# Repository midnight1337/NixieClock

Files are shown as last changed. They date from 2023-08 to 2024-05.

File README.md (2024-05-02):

# Nixie Clock

## Overwiev

Nixie clock is a retro style clock based on cool looking, vintage Nixie Tubes. <br/>

This project is inspired by GreatScott, however I've written my own code for driving this device, and did some changes in board by adding microswitches that allows user to change time manually.

Clock displays time in Hour::Minute segments. Board contains a RTC module that can track time with no power supply.

DS3231 clock library made by https://www.jarzebski.pl/arduino/komponenty/zegar-czasu-rzeczywistego-rtc-ds3231.html,
however I had to do some modifications for my needs.

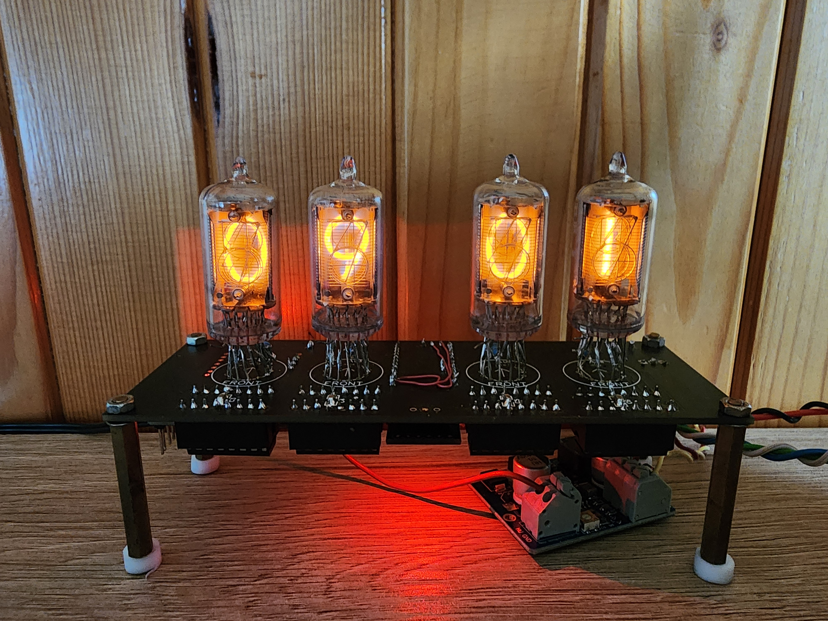
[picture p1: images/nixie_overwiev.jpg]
Overwiev


### Technologies and Development
- Arduino Pro Mini
- C++
- Electrical Engineering

## UML
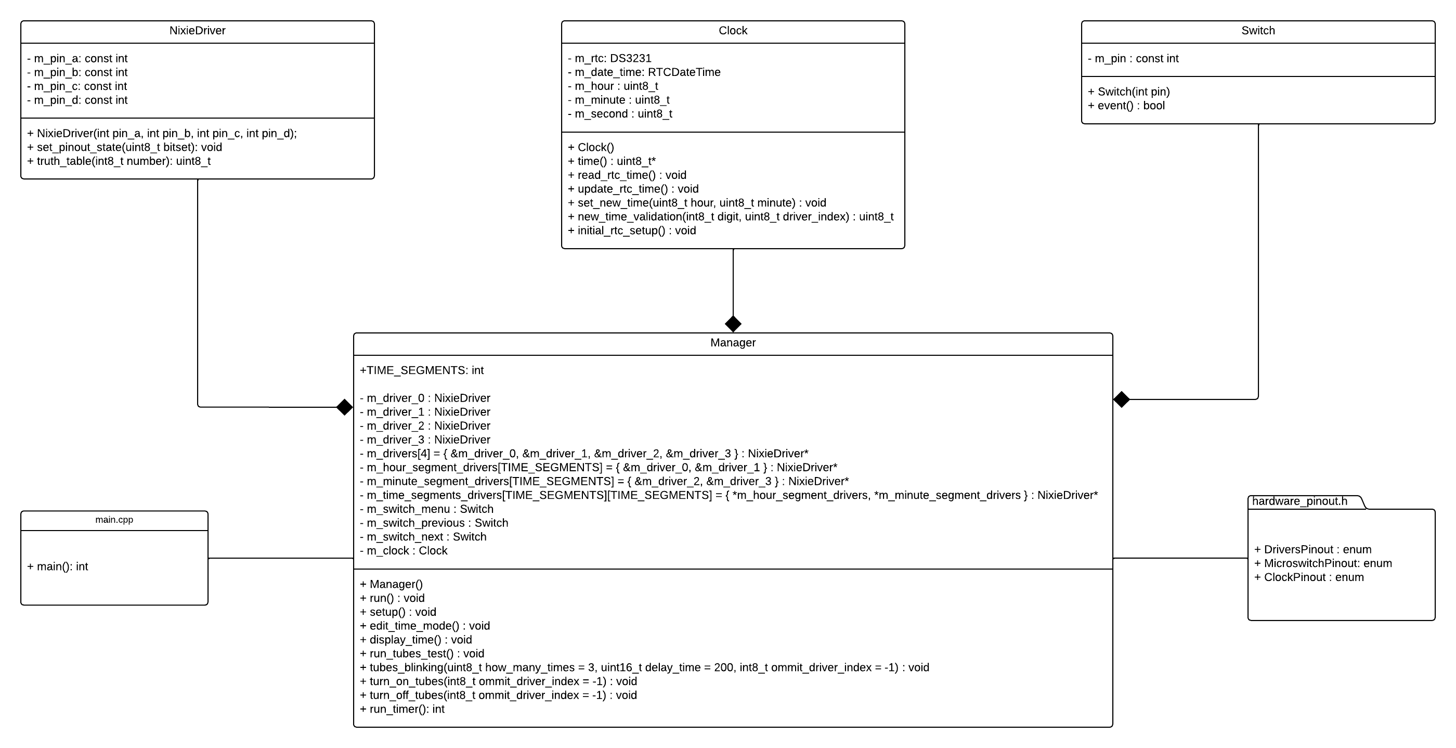
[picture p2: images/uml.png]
UML


## Schematic
...

## Project documentation

#### Testing nixie tubes:
At the beginning of my project I had to choose working Tubes by building simple driver circuit and running each digit from 0 to 9. As you may know they are very old and well worn. Some of them that I had, were damaged, or cathodes were burned out.
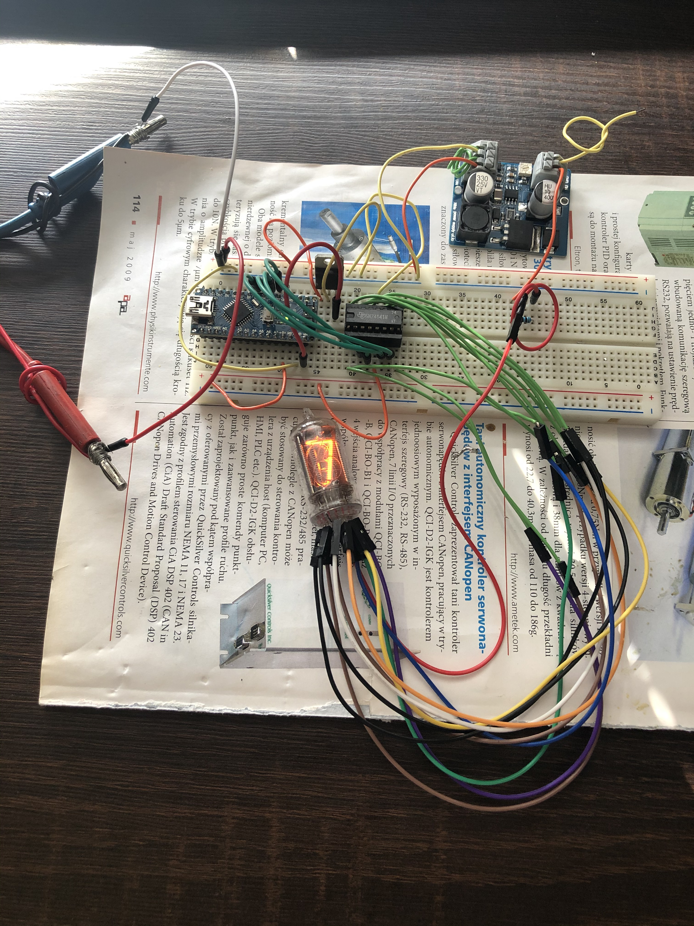
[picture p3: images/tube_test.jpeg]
Tube Test


#### Prototype:
First power up with everything on board.
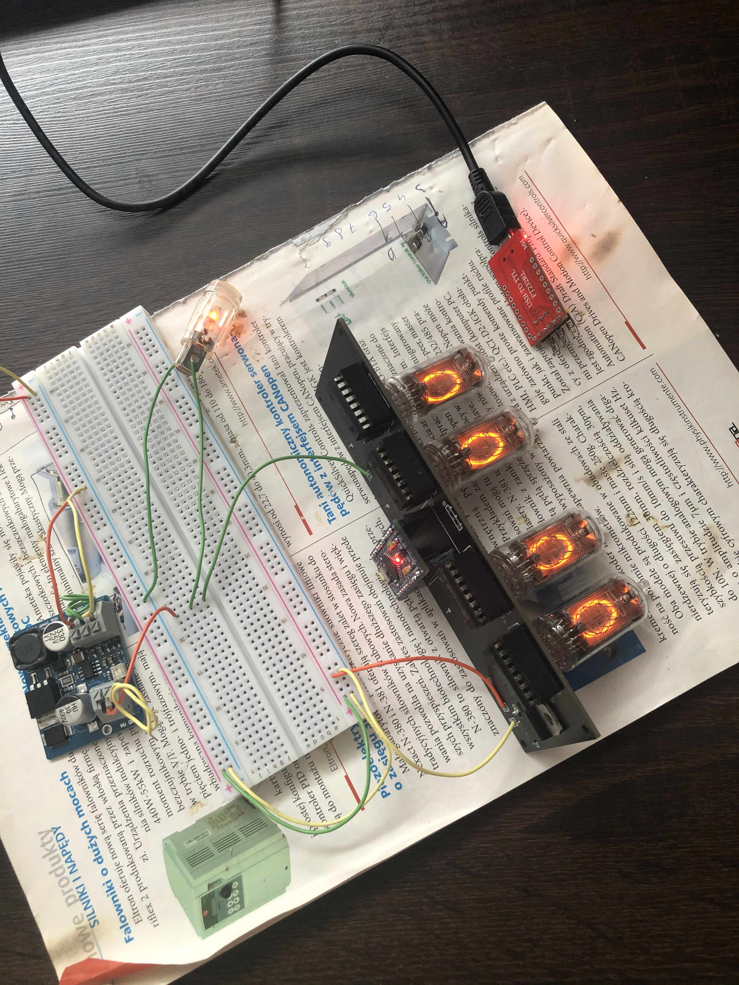
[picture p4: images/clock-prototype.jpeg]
Prototype


#### SN74141N Nixie Driver pinout:
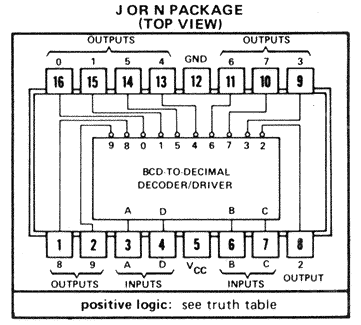
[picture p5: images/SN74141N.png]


#### SN74141N truth table:
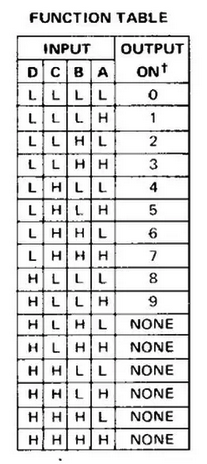
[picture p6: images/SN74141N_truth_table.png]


#### Nixie tube pinout:
Usually nixie tube structure has common anode and separted cathodes for each digit.
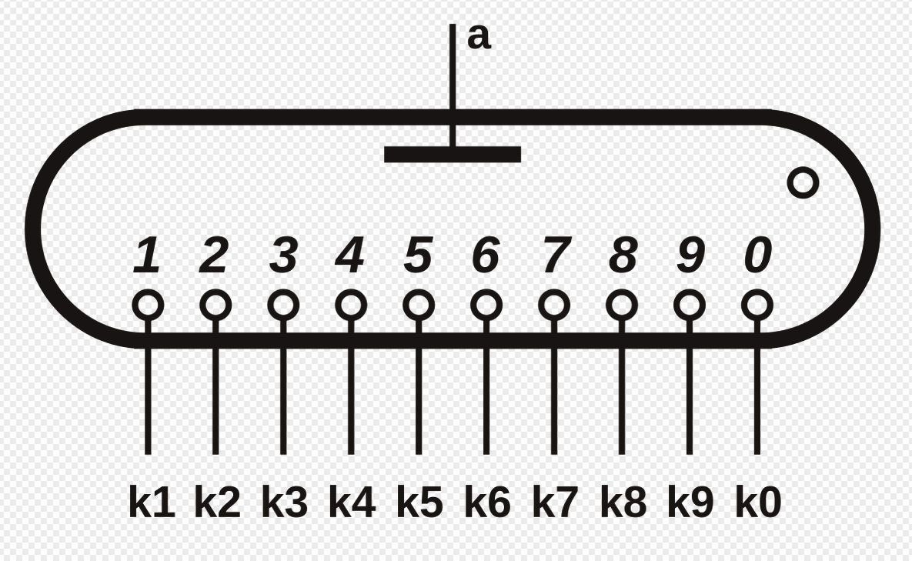
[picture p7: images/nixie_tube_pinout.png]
Tube


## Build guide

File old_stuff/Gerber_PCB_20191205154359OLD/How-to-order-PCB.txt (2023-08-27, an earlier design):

How to Order PCB

Please refer to:
https://docs.easyeda.com/en/PCB/Order-PCB

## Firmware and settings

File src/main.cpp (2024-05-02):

/**
 * @title: Nixie Clock
 * @author midnight1337
 * @brief A class-organised program, designed for running Clock based on Nixie Tubes.
 * @date: 18-12-2023
*/
#include "../include/manager.h"


int main()
{
  init();
  // Serial.begin(115200);

  Manager manager{};
  manager.setup();
  manager.run_tubes_test();

  while (true)
  {
    manager.run();
    delay(1000);
  }
}

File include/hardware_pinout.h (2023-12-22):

/* DEFINED DIGITAL MICROCONTROLLER PINOUTS */

/*
WIRING SETUP FOR ARDUINO PRO MINI

*/


enum DriversPinout
{
    // MCU -> SN74141N_0
    Pin_A0 = 3,  // LSB
    Pin_B0 = 4,
    Pin_C0 = 5,
    Pin_D0 = 6,  // MSB

    // MCU -> SN74141N_1
    Pin_A1 = 7,  // LSB
    Pin_B1 = 8,
    Pin_C1 = 9,
    Pin_D1 = 10,  // MSB

    // MCU -> SN74141N_2
    Pin_A2 = 11,  // LSB
    Pin_B2 = 12,
    Pin_C2 = 13,
    Pin_D2 = 14, // A0, MSB

    // MCU -> SN74141N_3
    Pin_A3 = 15, // LSB, (Analog 1)
    Pin_B3 = 16, // (Analog 2)
    Pin_C3 = 0,  // (PCB Analog 6 is wired with D0 (RX) so A6 can't be set as output directly??)
    Pin_D3 = 1, // MSB, (PCB Analog 7 is wired with D1 (TX) so A7 can't be set as output directly??)
};


enum MicroswitchPinout
{
    // // MCU -> microswitch
    Pin_MENU = 17,  // Analog 3, Edit Mode; Next digit.
    Pin_DOWN = 20,  // Analog 6, Digit down
    Pin_UP = 21,    // Analog 7, Digit up
};

// This enum is unused so far
enum ClockPinout
{
    Pin_SDA = 18,   // Analog 4
    Pin_SCL = 19,   // Analog 5
};

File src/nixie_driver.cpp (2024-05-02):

#include "../include/nixie_driver.h"

NixieDriver::NixieDriver(int pin_a, int pin_b, int pin_c, int pin_d) : 
m_pin_a(pin_a), 
m_pin_b(pin_b), 
m_pin_c(pin_c), 
m_pin_d(pin_d) 
{}

void NixieDriver::set_driver_mode(uint8_t bitset)
{
    /* Set pinouts of driver by given bitset, which represents a digit to be displayed */

    digitalWrite(m_pin_a, bitset & 0b0001); // LSB
    digitalWrite(m_pin_b, bitset & 0b0010);
    digitalWrite(m_pin_c, bitset & 0b0100);
    digitalWrite(m_pin_d, bitset & 0b1000); // MSB
}

uint8_t NixieDriver::truth_table(int8_t digit)
{
    /*
        Determine the truth table for driving a particular digit,
        Pinouts on PCB are reversed, in that case we need to reverse the truth table for drivers
    */
    uint8_t bitset = 0b0000;

    switch (digit)
    {
    case 0x00: // 0
        bitset = 0b0000;
        break;
    case 0x01: // |1001| => |0001|, bitset of '9' will display '1' on tube
        bitset = 0b1001;
        break;
    case 0x02: // 8 => 2
        bitset = 0b1000;
        break;
    case 0x03: // 7 => 3
        bitset = 0b1110;
        break;
    case 0x04: // 6 => 4
        bitset = 0b0110;
        break;
    case 0x05: // 5 => 5
        bitset = 0b0101;
        break;
    case 0x06: // 4 => 6
        bitset = 0b0100;
        break;
    case 0x07: // 3 => 7
        bitset = 0b0011;
        break;
    case 0x08: // 2 => 8
        bitset = 0b0010;
        break;
    case 0x09: // 1 => 9
        bitset = 0b0001;
        break;
    default:    // None state which simply turns tube off
        bitset = 0b1111;
        break;
    }
    
    return bitset;
}

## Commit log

2023-08-27 preparing file sfor refactor
    [Gerber_BoardOutline.GKO, Gerber_BottomLayer.GBL, Gerber_BottomPasteMaskLayer.GBP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]
2023-12-18 added DriverBase, working in progress in other classes
2023-12-19 added switch class
2023-12-19 working with switches and event loop
2023-12-19 update: switch, drivers etc.
2023-12-20 update README, some other changes
    [Gerber_BoardOutline.GKO, Gerber_BottomLayer.GBL, Gerber_BottomPasteMaskLayer.GBP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]
2023-12-20 remove deleted files from tracking
    [Gerber_BoardOutline.GKO, Gerber_BottomLayer.GBL, Gerber_BottomPasteMaskLayer.GBP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]
2023-12-27 Changed turn on and off tubes methods according to grouped drivers
2023-12-28 Time format logic according to drivers group, some other changes like naming refactor
2024-01-04 switch fix
2024-05-03 timer, some other small changes aka refactoring
